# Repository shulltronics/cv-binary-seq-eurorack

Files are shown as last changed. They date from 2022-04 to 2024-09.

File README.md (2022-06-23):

## CV Binary Sequencer

This is a 1U Eurorack module that maps four trigger inputs to four CV outputs.
Inspired by the CV capabilities of Pamela's New Workout, _cv-binary-sequencer_ aims to produce customizable and intricate CV outputs for controlling other modules. There is a mapping of the 16 possible trigger inputs to a combination of CV outputs. On each trigger edge of an input CVs will change to the value specified by the mapping.

_cv-binary-seq_ can be used to multiplex 4 trigger inputs (e.g. 4 pads from a Beatstep Pro, or ) to create 16 different combinations of 4 CV outputs. This could be utilized to create 16 drum sounds from one module, or to create a 16 step melodic sequence that changes pitch, decay rate, and tone on each step.

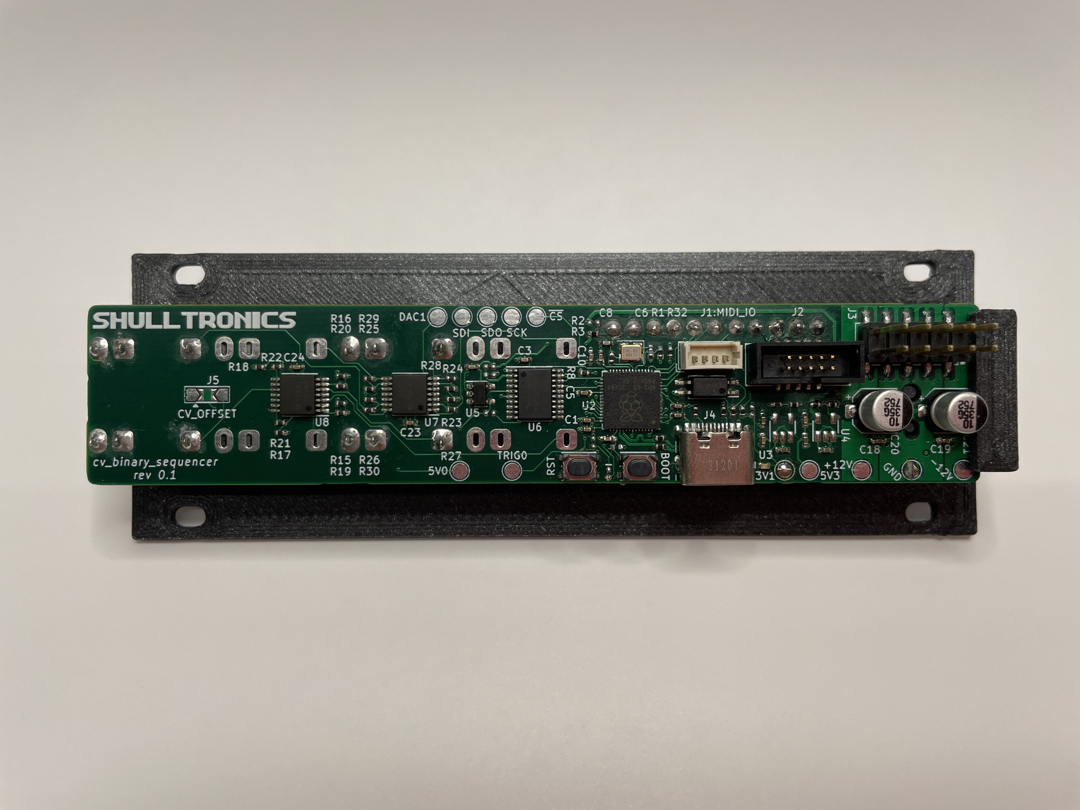
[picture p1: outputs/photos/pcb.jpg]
PCB Assembly

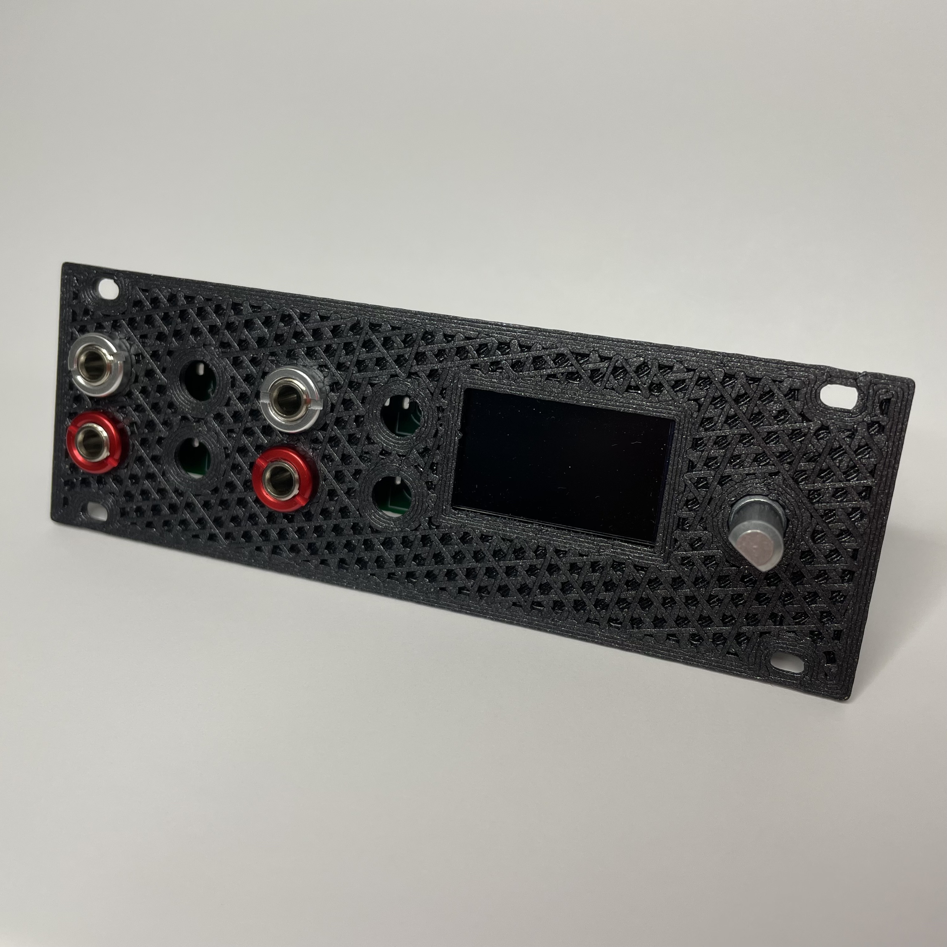
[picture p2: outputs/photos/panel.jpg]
Front Panel


### Goals
- [ ] - Configurable input trigger (rising, falling, etc). 
- [ ] - CV outputs similar to PNW (constant value, exponential rise/fall, period wave, etc).
- [ ] - Possibly add different input modes (binary mapping input to output, trigger input to cycle through mapping, etc).

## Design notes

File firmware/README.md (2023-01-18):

Firmware for CV Binary Sequencer
================================
### By Shulltronics

## Feature testing
- [X] USB firmware upload (**TODO** make connector double sided)
- [ ] BOOTSEL button (**Issue** don't think this will work without the ROM chip)
- [ ] USB Serial Comms (**Issue** don't think this will work without the ROM chip)
- [X] Status LED over GPIO
- [X] LCD screen over SPI (**TODO** Test various SPI speeds, look at signal integrity)
- [X] Encoder button over GPIO
- [ ] Encoder rotation (over PIO?)
- [ ] MIDI IO over UART
- [ ] Trigger inputs over Interrupts
- [X] DAC comms over SPI (**TODO** Improve driver)

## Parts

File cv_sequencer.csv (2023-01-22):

Source: | /home/carstentb/Projects/KiCad/cv-binary-seq-eurorack/cv_sequencer.kicad_sch
Date: | Sun 06 Nov 2022 12:24:42 PM EST
Tool: | Eeschema (6.0.9)
Generator: | /home/carstentb/.local/share/kicad/6.0/plugins/bom_csv_grouped_by_value.py
Component Count: | 90
Collated Components:
Item | Reference(s) | Qty | Distributor | Dist. PN | Value | SPN | Val
1 | C1, C2, C4, C5, C7, C9, C10, C11, C12, C14, C18, C19 | 12 | =FILTER('Parts Inventory'!G:H, 'Parts Inventory'!A:A=3089_Capacitor_100n_16V_0402) |  |  | 3089_Capacitor_100n_16V_0402 | 100n
2 | C3, C22, C23, C24 | 4 | =FILTER('Parts Inventory'!G:H, 'Parts Inventory'!A:A=3089_Capacitor_100n_16V_0402) |  |  | 3089_Capacitor_100n_16V_SMD | 100n
3 | C6, C8 | 2 | =FILTER('Parts Inventory'!G:H, 'Parts Inventory'!A:A=4003_Capacitor_22pF_50V_0402) |  |  | 4003_Capacitor_22pF_50V_0402 | 22pF
4 | C13, C15, C16, C17 | 4 | =FILTER('Parts Inventory'!G:H, 'Parts Inventory'!A:A=4035_Capacitor_2u2_25V_0402) |  |  | 4035_Capacitor_2u2_25V_0402 | 2u2
5 | C20, C21 | 2 | =FILTER('Parts Inventory'!G:H, 'Parts Inventory'!A:A=4031_Capacitor_10u_35V_SMD) |  |  | 4031_Capacitor_10u_35V_SMD | 10u
6 | E1 | 1 | =FILTER('Parts Inventory'!G:H, 'Parts Inventory'!A:A=4025_Encoder_Switch_SMD) |  |  | 4025_Encoder_Switch_SMD
7 | J1 | 1 | =FILTER('Parts Inventory'!G:H, 'Parts Inventory'!A:A=4029_Connector_PicoBlade_4pos_Vert_THT) |  |  | :MIDI_IO
8 | J2 | 1 | =FILTER('Parts Inventory'!G:H, 'Parts Inventory'!A:A=4005_SWD_Header) |  |  | SWD
9 | J3 | 1 | =FILTER('Parts Inventory'!G:H, 'Parts Inventory'!A:A=3086_Connector_Eurorack_Power) |  |  | 3086_Connector_Eurorack_Power
10 | J4 | 1 | =FILTER('Parts Inventory'!G:H, 'Parts Inventory'!A:A=3096_USBC_RA_SMD) |  |  | 3096_USBC_RA_SMD
11 | J5 | 1 | =FILTER('Parts Inventory'!G:H, 'Parts Inventory'!A:A=3046_Header_Male_Vert_3pos) |  |  | CV_OFFSET
12 | J6, J7, J8, J9, J10, J11, J12, J13 | 8 | =FILTER('Parts Inventory'!G:H, 'Parts Inventory'!A:A=3085_MiniJack_Thonk_Vert) |  |  | 3085_MiniJack_Thonk_Vert
13 | R1, R8, R32 | 3 | =FILTER('Parts Inventory'!G:H, 'Parts Inventory'!A:A=4008_Resistor_SMD_10k_0.125W_1%) |  |  | 4008_Resistor_SMD_10k_0.125W_1% | 10k
14 | R2, R38 | 2 | =FILTER('Parts Inventory'!G:H, 'Parts Inventory'!A:A=4021_Resistor_SMD_Jumper) |  |  | DNP | 0
15 | R3, R36 | 2 | =FILTER('Parts Inventory'!G:H, 'Parts Inventory'!A:A=4021_Resistor_SMD_Jumper) |  |  | 4021_Resistor_SMD_Jumper | 0
16 | R4, R5 | 2 | =FILTER('Parts Inventory'!G:H, 'Parts Inventory'!A:A=4010_Resistor_SMD_1k_0.125W_1%) |  |  | 4010_Resistor_SMD_1k_0.125W_1% | 1k
17 | R6, R7 | 2 | =FILTER('Parts Inventory'!G:H, 'Parts Inventory'!A:A=4011_Resistor_SMD_27_0.125W_1%) |  |  | 4011_Resistor_SMD_27_0.125W_1% | 27
18 | R9, R11 | 2 | =FILTER('Parts Inventory'!G:H, 'Parts Inventory'!A:A=4016_Resistor_SMD_27k_0.125W_1%) |  |  | 4016_Resistor_SMD_27k_0.125W_1% | 27k
19 | R10 | 1 | =FILTER('Parts Inventory'!G:H, 'Parts Inventory'!A:A=4033_Resistor_SMD_18k_0.125W_1%) |  |  | 4033_Resistor_SMD_18k_0.125W_1% | 18k
20 | R12 | 1 | =FILTER('Parts Inventory'!G:H, 'Parts Inventory'!A:A=4034_Resistor_SMD_8k2_0.125W_1%) |  |  | 4034_Resistor_SMD_8k2_0.125W_1% | 8k2
21 | R13, R14 | 2 | =FILTER('Parts Inventory'!G:H, 'Parts Inventory'!A:A=4009_Resistor_SMD_5k1_0.10W_1%) |  |  | 4009_Resistor_SMD_5k1_0.10W_1% | 5k1
22 | R15, R16, R17, R18 | 4 | =FILTER('Parts Inventory'!G:H, 'Parts Inventory'!A:A=4023_Resistor_SMD_56k_0.125W_1%) |  |  | 4023_Resistor_SMD_56k_0.125W_1% | 56k
23 | R19, R20, R21, R22 | 4 | =FILTER('Parts Inventory'!G:H, 'Parts Inventory'!A:A=4022_Resistor_SMD_120k_0.125W_1%) |  |  | 4022_Resistor_SMD_120k_0.125W_1% | 120k
24 | R23, R24, R25, R26, R27, R28, R29, R30 | 8 | =FILTER('Parts Inventory'!G:H, 'Parts Inventory'!A:A=4006_Resistor_SMD_68k_0.125W_1%) |  |  | 4006_Resistor_SMD_68k_0.125W_1% | 68k
25 | R31, R33 | 2 | =FILTER('Parts Inventory'!G:H, 'Parts Inventory'!A:A=4030_Resistor_SMD_220_0.125W_1%) |  |  | 4030_Resistor_SMD_220_0.125W_1% | 220
26 | R34, R35 | 2 | =FILTER('Parts Inventory'!G:H, 'Parts Inventory'!A:A=4038_Resistor_SMD_100_0.125W_1%) |  |  | 4038_Resistor_SMD_100_0.125W_1% | 100
27 | R37 | 1 | =FILTER('Parts Inventory'!G:H, 'Parts Inventory'!A:A=4021_Resistor_SMD_Jumper) |  |  | JMP | 0
28 | SW1 | 1 | =FILTER('Parts Inventory'!G:H, 'Parts Inventory'!A:A=4012_PushButton_NO_SMD) |  |  | RST
29 | SW2 | 1 | =FILTER('Parts Inventory'!G:H, 'Parts Inventory'!A:A=4012_PushButton_NO_SMD) |  |  | BOOT
30 | U1 | 1 | =FILTER('Parts Inventory'!G:H, 'Parts Inventory'!A:A=3097_TFT_Display_SPI) |  |  | 3097_TFT_Display_SPI | 1.14" TFT Display
31 | U2 | 1 | =FILTER('Parts Inventory'!G:H, 'Parts Inventory'!A:A=4002_RP2040) |  |  | 4002_RP2040
32 | U3, U4 | 2 | =FILTER('Parts Inventory'!G:H, 'Parts Inventory'!A:A=4032_Adjustable_Reg_200mA_SOT-23-5) |  |  | 4032_Adjustable_Reg_200mA_SOT-23-5
33 | U5 | 1 | =FILTER('Parts Inventory'!G:H, 'Parts Inventory'!A:A=4014_Voltage_Reference_5V_SOT23-6) |  |  | 4014_Voltage_Reference_5V_SOT23-6
34 | U6 | 1 | =FILTER('Parts Inventory'!G:H, 'Parts Inventory'!A:A=4001_MCP48FEB24_DAC) |  |  | 4001_MCP48FEB24_DAC
35 | U7, U8 | 2 | =FILTER('Parts Inventory'!G:H, 'Parts Inventory'!A:A=3099_TL074CPW_SMD) |  |  | 3099_TL074CPW_SMD | TL074
36 | U9 | 1 | =FILTER('Parts Inventory'!G:H, 'Parts Inventory'!A:A=4028_OptoIsolator_TLP290) |  |  | 4028_OptoIsolator_TLP290
37 | U10 | 1 | =FILTER('Parts Inventory'!G:H, 'Parts Inventory'!A:A=4036_LED_GRN_SMD) |  |  | PWR
38 | U11 | 1 | =FILTER('Parts Inventory'!G:H, 'Parts Inventory'!A:A=4037_LED_YLW_SMD) |  |  | STAT
39 | Y1 | 1 | =FILTER('Parts Inventory'!G:H, 'Parts Inventory'!A:A=4004-Crystal-12MHz_GND24) |  |  | 4004-Crystal-12MHz_GND24 | 12.00MHz

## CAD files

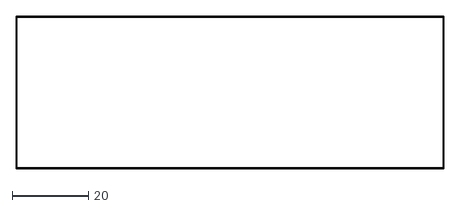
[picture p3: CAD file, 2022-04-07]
outputs/panel_dxf/cv_sequencer-User_Eco1.dxf
111.9 x 39.8

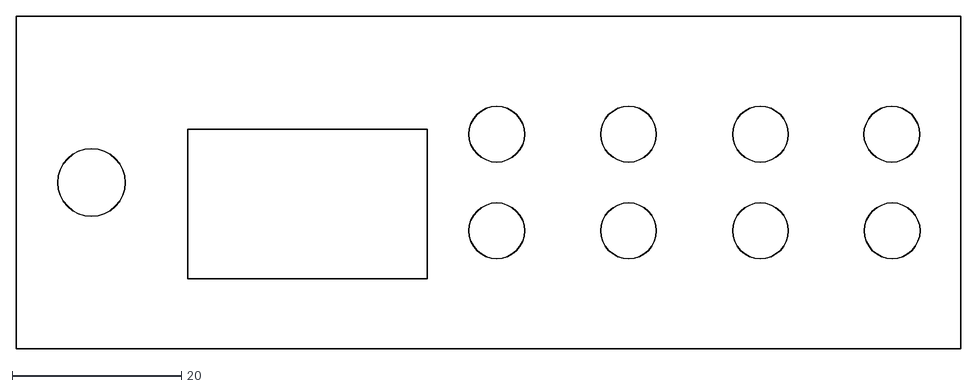
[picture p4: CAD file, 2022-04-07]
outputs/panel_dxf/drawing.dxf
111.8 x 39.4

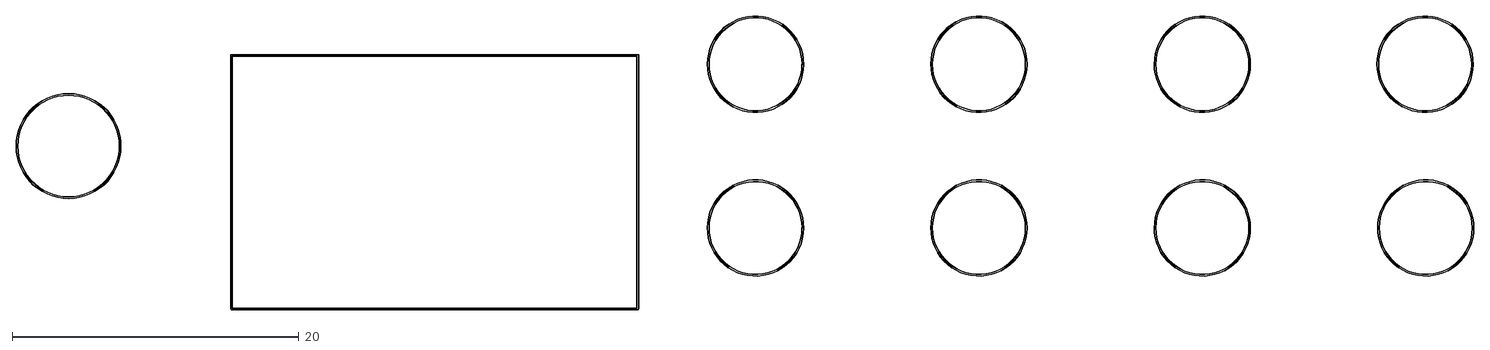
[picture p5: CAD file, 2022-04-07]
outputs/panel_dxf/cv_sequencer-User_Drawings.dxf
101.8 x 20.5

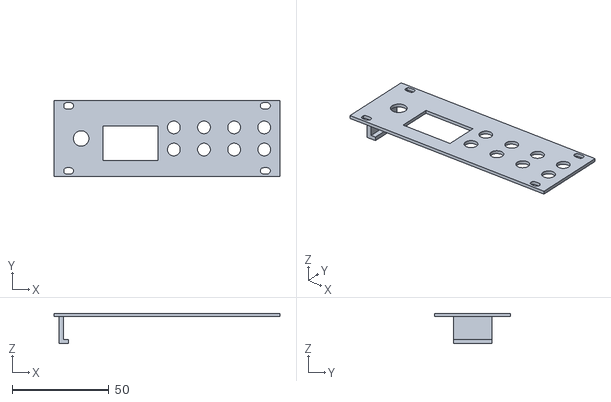
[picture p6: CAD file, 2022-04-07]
outputs/panel_dxf/panel_with_support.stl
116.9 x 39.5 x 15.6

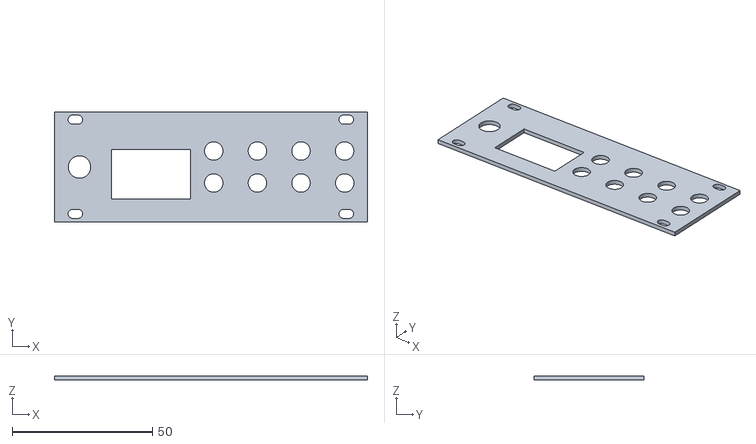
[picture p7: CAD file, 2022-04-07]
outputs/panel_dxf/panel.stl
111.8 x 39.4 x 1.60

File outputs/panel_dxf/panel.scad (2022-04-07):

_DELTA = 0.01;

ONE_HP = 0.2*25.4;
ONE_U  = 39.65;
// approximately equal to a standard PCB thickness
THICKNESS = 1.6;
MODULE_WIDTH = 23*ONE_HP;

// the main facade body
//   Process: plot User Drawings layer from KiCAD (contains outline
//     and holes for jacks, encoders, etc). Open that in Inkscape,
//     process circles using "Object->Object to Path", then select path,
//     process using "Segments to lines", then save as R14 DXF to import here.
module main() {
    linear_extrude(height=THICKNESS)
        import(file="drawing.dxf");
}

module mounting_hole(x_offset=0, y_offset=0) {
    $fn = 36;
    MOUNTING_HOLE_DIAMETER = 3.2;
    translate([x_offset, y_offset, THICKNESS/2])
        hull() {
            translate([-1, 0, 0])
                cylinder(THICKNESS+_DELTA, MOUNTING_HOLE_DIAMETER/2, MOUNTING_HOLE_DIAMETER/2, center=true);
            translate([1, 0, 0])
                cylinder(THICKNESS+_DELTA, MOUNTING_HOLE_DIAMETER/2, MOUNTING_HOLE_DIAMETER/2, center=true);
        }
}

module three() {
    
}

difference() {  
    translate([1*ONE_HP, 0, 0])
        main();
    mounting_hole(7.5, 3);
    mounting_hole(7.5, ONE_U-3);
    mounting_hole(MODULE_WIDTH-7.5, 3);
    mounting_hole(MODULE_WIDTH-7.5, ONE_U-3);
}

// extra space to add support
cube([ONE_HP+10*_DELTA, ONE_U-0.2, THICKNESS]);
translate([2.5, 0, 0]) {
    // support
    support_height = 12;
    translate([ONE_HP/4, ONE_U/2, -support_height/2])
        cube([ONE_HP/2, ONE_U/2, support_height], center=true);
    translate([ONE_HP/2, ONE_U/2, -support_height-1])
        cube([ONE_HP, ONE_U/2, 2], center=true);
}

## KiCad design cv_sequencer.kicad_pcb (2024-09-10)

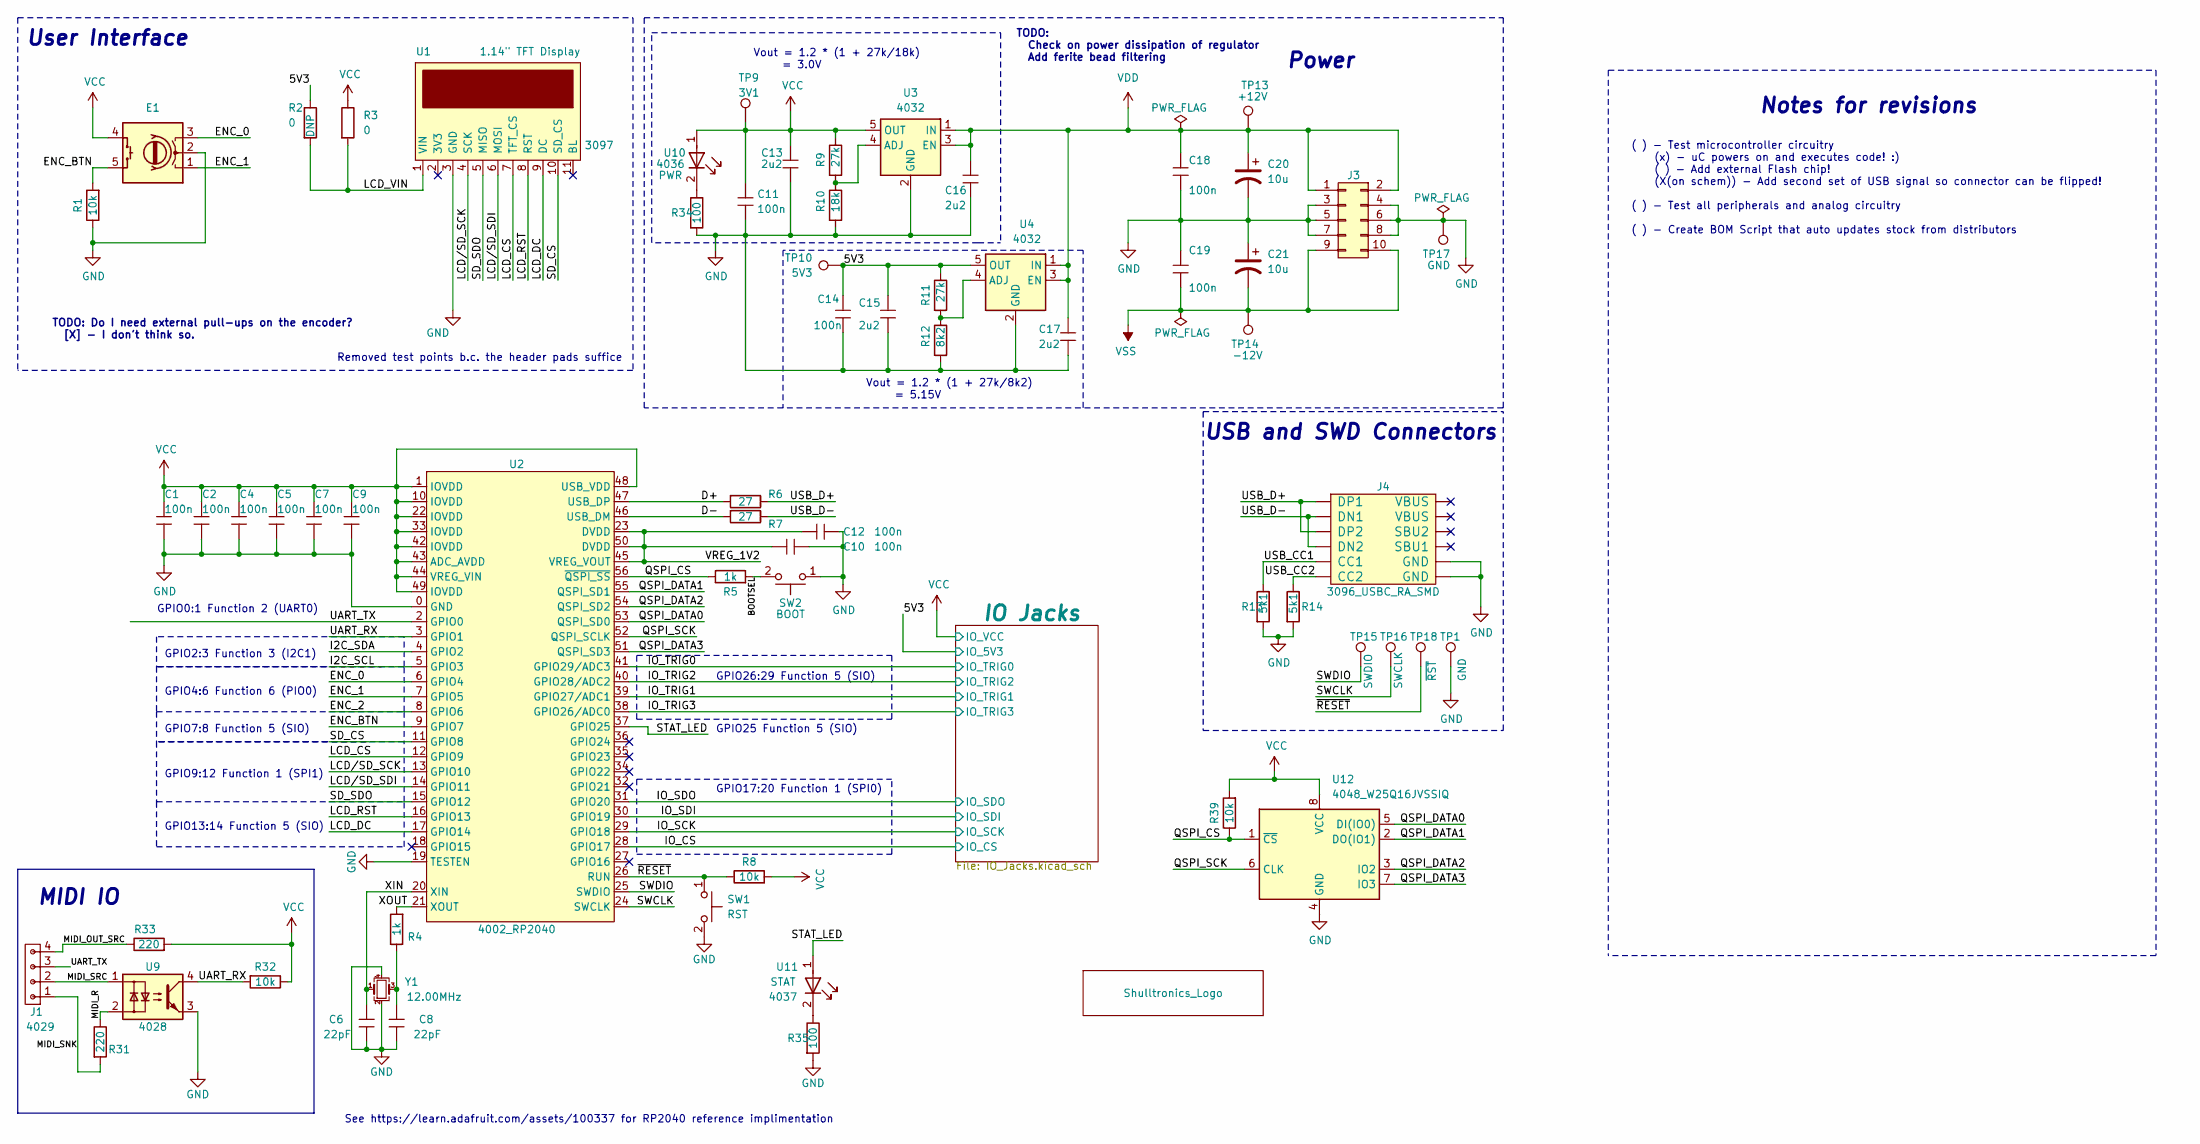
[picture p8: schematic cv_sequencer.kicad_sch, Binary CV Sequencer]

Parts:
C1, C2, C4, C5, C7, C9, C10, C11, C12, C14, C18, C19: 3089_Capacitor_100n_16V_0402; C_0402_HandSolder
C6, C8: 4003_Capacitor_22pF_50V_0402; C_0402_HandSolder
C13, C15, C16, C17: 4035_Capacitor_2u2_25V_0402; C_0402_HandSolder
C20, C21: 4031_Capacitor_10u_35V_SMD; 3088_Capacitor_10u_50V_SMD
E1: 4025_Encoder_Switch_SMD; 4025_Encoder_PEC11S
J1: :MIDI_IO; 4029_PicoBlade_4pos_Vert_THT
J3: 3086_Connector_Eurorack_Power; 3086_SMD_Eurorack_Power
J4: 3096_USBC_RA_SMD; 3096_USBC_RA
L1: Shulltronics_Logo
R1, R8, R32, R39: 4008_Resistor_SMD_10k_0.125W_1%; RES-0402
R2: DNP; RES-0402
R3: 4021_Resistor_SMD_Jumper; RES-0402
R4, R5: 4010_Resistor_SMD_1k_0.125W_1%; RES-0402
R6, R7: 4011_Resistor_SMD_27_0.125W_1%; RES-0402
R9, R11: 4016_Resistor_SMD_27k_0.125W_1%; RES-0402
R10: 4033_Resistor_SMD_18k_0.125W_1%; RES-0402
R12: 4034_Resistor_SMD_8k2_0.125W_1%; RES-0402
R13, R14: 4009_Resistor_SMD_5k1_0.10W_1%; RES-0402
R31, R33: 4030_Resistor_SMD_220_0.125W_1%; RES-0402
R34, R35: 4038_Resistor_SMD_100_0.125W_1%; RES-0402
SW1: RST; 4012_PushButton_NO_SMD
SW2: BOOT; 4012_PushButton_NO_SMD
TP1, TP17: GND; TestPoint_Pad_D2.0mm
TP9: 3V1; TestPoint_Pad_D2.0mm
TP10: 5V3; TestPoint_Pad_D2.0mm
TP13: +12V; TestPoint_Pad_D2.0mm
TP14: -12V; TestPoint_Pad_D2.0mm
TP15: SWDIO; TestPoint_Pad_D2.0mm
TP16: SWCLK; TestPoint_Pad_D2.0mm
TP18: ~{RST}; TestPoint_Pad_D2.0mm
U1: 3097_TFT_Display_SPI
U2: 4002_RP2040; 4002_RP2040_QFN-56-7x7mm_P0.4mm
U3, U4: 4032_Adjustable_Reg_200mA_SOT-23-5; SOT-23-5
U9: 4028_OptoIsolator_TLP290; 4028_OptoIsolator_TLP290_SOP-4
U10: PWR; LED_0402
U11: STAT; LED_0402
U12: 4048_W25Q16JVSSIQ; 4048_16Mb_Flash_SOIC8
Y1: 4004-Crystal-12MHz_GND24; 4004-Crystal-12MHz-4Pin_2.5x2.0mm

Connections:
/5V3: C14.2, C15.2, R2.1, R11.1, TP10.1, U4.5 (OUT); also elsewhere on the board
/BOOTSEL: R5.2, SW2.2
/D+: R6.2, U2.47 (USB_DP)
/D-: R7.2, U2.46 (USB_DM)
/ENC_0: E1.3, U2.6 (GPIO4)
/ENC_1: E1.1, U2.7 (GPIO5)
/ENC_2: U2.8 (GPIO6)
/ENC_BTN: E1.5, R1.2, U2.9 (GPIO7)
/I2C_SCL: U2.5 (GPIO3)
/I2C_SDA: U2.4 (GPIO2)
/IO_CS: U2.28 (GPIO17); also elsewhere on the board
/IO_SCK: U2.29 (GPIO18); also elsewhere on the board
/IO_SDI: U2.30 (GPIO19); also elsewhere on the board
/IO_SDO: U2.31 (GPIO20); also elsewhere on the board
/IO_TRIG0: U2.41 (GPIO29/ADC3); also elsewhere on the board
/IO_TRIG1: U2.39 (GPIO27/ADC1); also elsewhere on the board
/IO_TRIG2: U2.40 (GPIO28/ADC2); also elsewhere on the board
/IO_TRIG3: U2.38 (GPIO26/ADC0); also elsewhere on the board
/LCD_CS: U1.7 (TFT_CS), U2.12 (GPIO9)
/LCD_DC: U1.9 (DC), U2.17 (GPIO14)
/LCD_RST: U1.8 (RST), U2.16 (GPIO13)
/LCD_VIN: R2.2, R3.2, U1.1 (VIN)
/LCD/SD_SCK: U1.4 (SCK), U2.13 (GPIO10)
/LCD/SD_SDI: U1.6 (MOSI), U2.14 (GPIO11)
/MIDI_OUT_SRC: J1.4, R33.1
/MIDI_R: R31.1, U9.2
/MIDI_SNK: J1.1, R31.2
/MIDI_SRC: J1.2, U9.1
/QSPI_CS: R5.1, R39.1, U2.56 (~QSPI_SS), U12.1 (~CS)
/QSPI_DATA0: U2.53 (QSPI_SD0), U12.5 (DI(IO0))
/QSPI_DATA1: U2.55 (QSPI_SD1), U12.2 (DO(IO1))
/QSPI_DATA2: U2.54 (QSPI_SD2), U12.3 (IO2)
/QSPI_DATA3: U2.51 (QSPI_SD3), U12.7 (IO3)
/QSPI_SCK: U2.52 (QSPI_SCLK), U12.6 (CLK)
/SD_CS: U1.10 (SD_CS), U2.11 (GPIO8)
/SD_SDO: U1.5 (MISO), U2.15 (GPIO12)
/STAT_LED: U2.37 (GPIO25), U11.1 (A)
/SWCLK: TP16.1, U2.24 (SWCLK)
/SWDIO: TP15.1, U2.25 (SWDIO)
/UART_RX: R32.2, U2.3 (GPIO1), U9.4
/UART_TX: J1.3, U2.2 (GPIO0)
/USB_CC1: J4.A5 (CC1), R13.1
/USB_CC2: J4.B5 (CC2), R14.1
/USB_D+: J4.A6 (DP1), J4.B6 (DP2), R6.1
/USB_D-: J4.A7 (DN1), J4.B7 (DN2), R7.1
/VREG_1V2: C10.1, C12.1, U2.23 (DVDD), U2.45 (VREG_VOUT), U2.50 (DVDD)
/XIN: C6.2, U2.20 (XIN), Y1.1
/XOUT: R4.2, U2.21 (XOUT)
/~RESET: R8.1, SW1.1, TP18.1, U2.26 (RUN)
GND: C1.1, C2.1, C4.1, C5.1, C6.1, C7.1, C8.1, C9.1, C10.2, C11.1, C12.2, C13.1, C14.1, C15.1, C16.1, C17.1, C18.1, C19.2, C20.2, C21.1, E1.2, J3.3, J3.4, J3.5, J3.6, J3.7, J3.8, J4.A1/B12 (GND), J4.B1/A12 (GND), R1.1, R10.2, R12.2, R13.2, R14.2, R34.2, R35.2, SW1.2, SW2.1, TP1.1, TP17.1, U1.3 (GND), U2.0 (GND), U2.19 (TESTEN), U3.2 (GND), U4.2 (GND), U9.3, U12.4 (GND), Y1.2, Y1.4; also elsewhere on the board
unnamed: C8.2, R4.1, Y1.3
unnamed: R9.2, R10.1, U3.4 (ADJ)
unnamed: R11.2, R12.1, U4.4 (ADJ)
unnamed: R34.1, U10.2 (K)
unnamed: R35.1, U11.2 (K)
VCC: C1.2, C2.2, C4.2, C5.2, C7.2, C9.2, C11.2, C13.2, E1.4, R3.1, R8.2, R9.1, R32.1, R33.2, R39.2, TP9.1, U2.1 (IOVDD), U2.10 (IOVDD), U2.22 (IOVDD), U2.33 (IOVDD), U2.42 (IOVDD), U2.43 (ADC_AVDD), U2.44 (VREG_VIN), U2.48 (USB_VDD), U2.49 (IOVDD), U3.5 (OUT), U10.1 (A), U12.8 (VCC); also elsewhere on the board
VDD: C16.2, C17.2, C18.2, C20.1, J3.1, J3.2, TP13.1, U3.1 (IN), U3.3 (EN), U4.1 (IN), U4.3 (EN); also elsewhere on the board
VSS: C19.1, C21.2, J3.9, J3.10, TP14.1; also elsewhere on the board

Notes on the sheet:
GPIO25 Function 5 (SIO)
Vout = 1.2 * (1 + 27k/8k2) = 5.15V
GPIO2:3 Function 3 (I2C1)
GPIO17:20 Function 1 (SPI0)
Removed test points b.c. the header pads suffice
See https://learn.adafruit.com/assets/100337 for RP2040 reference implimentation
Vout = 1.2 * (1 + 27k/18k) = 3.0V
GPIO7:8 Function 5 (SIO)
USB and SWD Connectors
( ) - Test microcontroller circuitry (x) - uC powers on and executes code! :) ( ) - Add external Flash chip! (X(on schem)) - Add second set of USB signal so connector can be flipped! ( ) - Test all peripherals and analog circuitry ( ) - Create BOM Script that auto updates stock from distributors
GPIO9:12 Function 1 (SPI1)
TODO: Do I need external pull-ups on the encoder? [X] - I don't think so.
Notes for revisions
MIDI IO
GPIO0:1 Function 2 (UART0)
GPIO26:29 Function 5 (SIO)
Power
TODO: Check on power dissipation of regulator Add ferite bead filtering
GPIO13:14 Function 5 (SIO)
GPIO4:6 Function 6 (PIO0)
User Interface

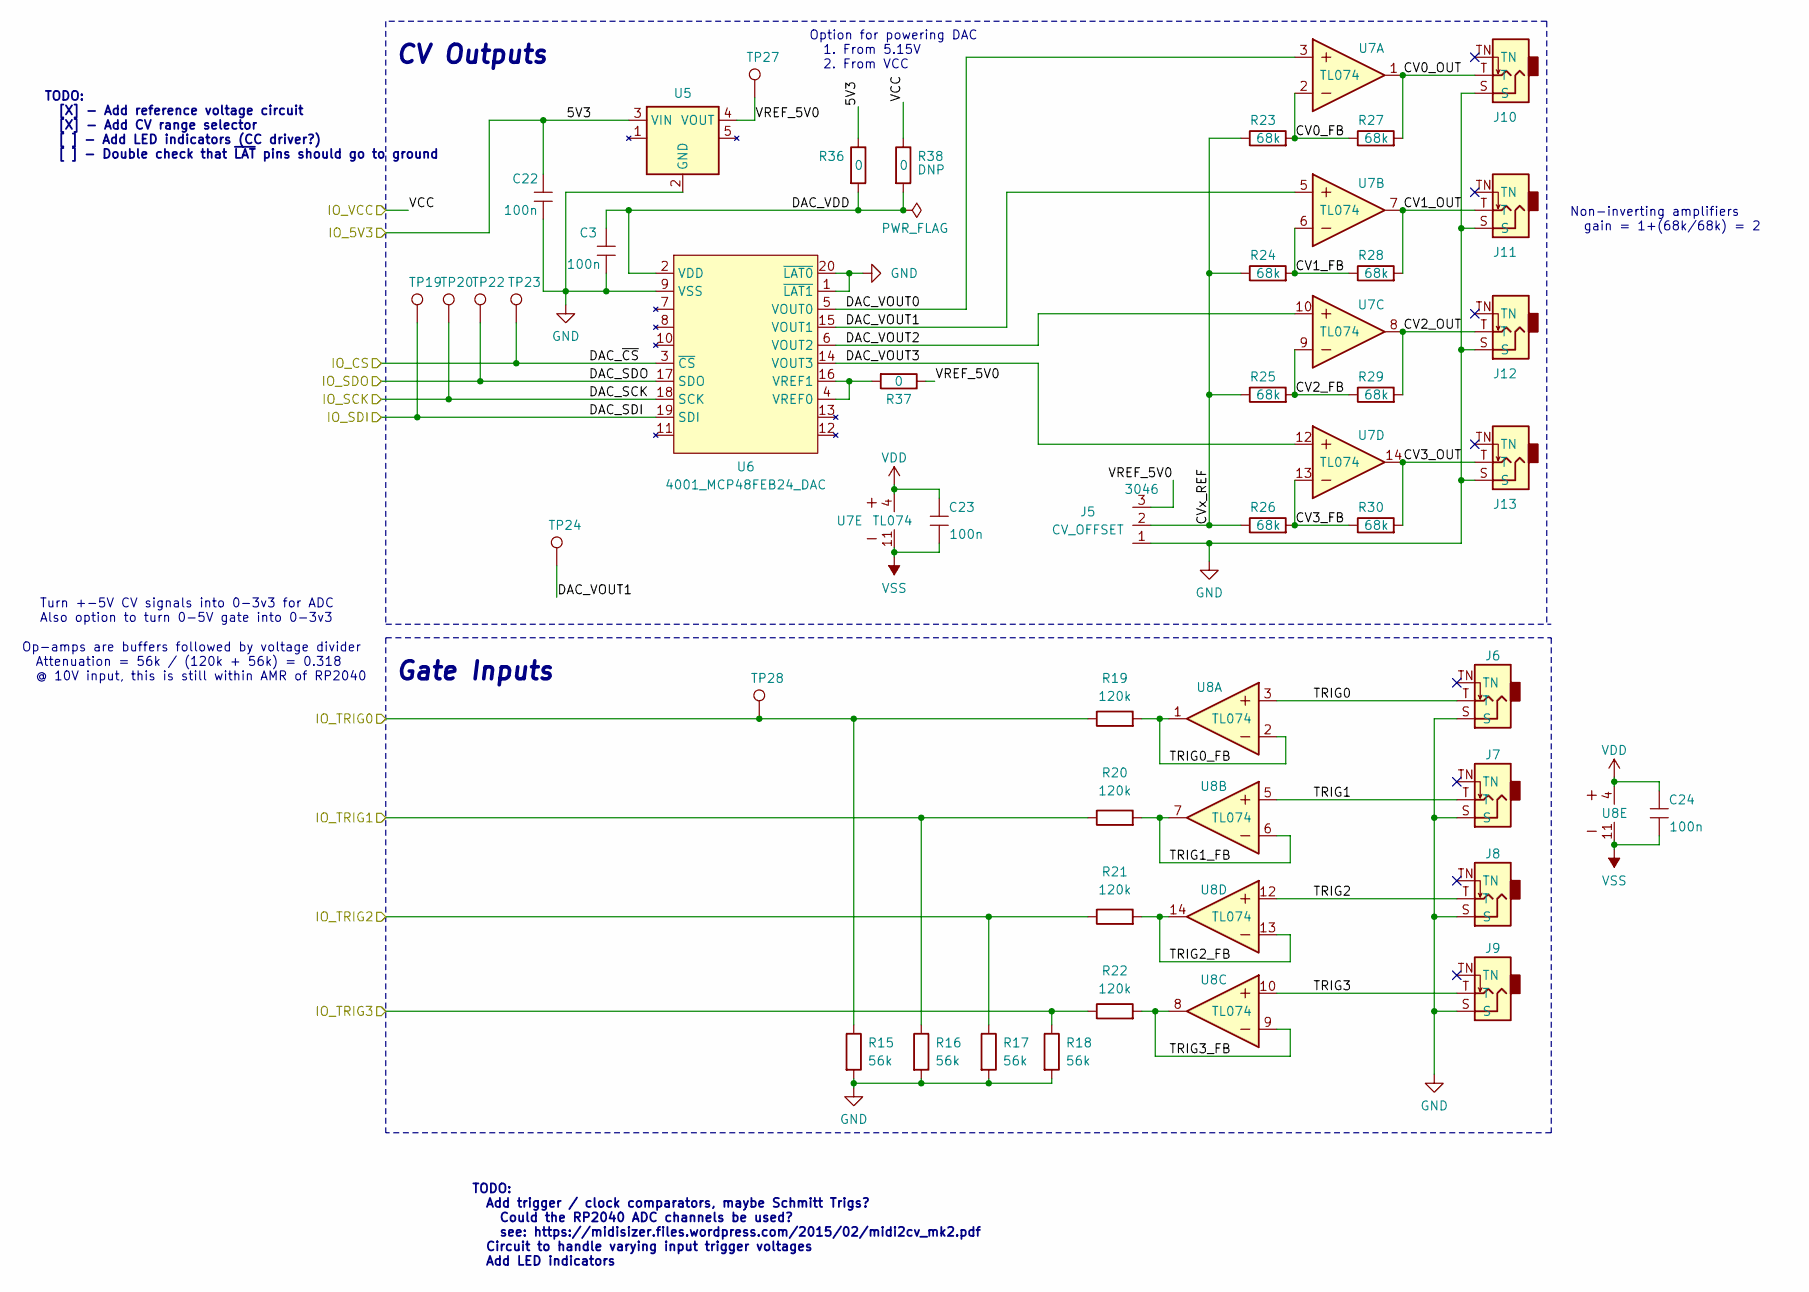
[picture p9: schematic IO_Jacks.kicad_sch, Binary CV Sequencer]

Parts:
C3, C22, C23, C24: 3089_Capacitor_100n_16V_SMD; C_0402_HandSolder
J5: CV_OFFSET; SMD_SolderJumper-3
J6, J7, J8, J9, J10, J11, J12, J13: 3085_MiniJack_Thonk_Vert
R15, R16, R17, R18: 4023_Resistor_SMD_56k_0.125W_1%; RES-0402
R19, R20, R21, R22: 4022_Resistor_SMD_120k_0.125W_1%; RES-0402
R23, R24, R25, R26, R27, R28, R29, R30: 4006_Resistor_SMD_68k_0.125W_1%; RES-0402
R36: 4021_Resistor_SMD_Jumper; RES-0402
R37: JMP; RES-0402
R38: DNP; RES-0402
TP19: SDI; TestPoint_Pad_D2.0mm
TP20: SCK; TestPoint_Pad_D2.0mm
TP22: SDO; TestPoint_Pad_D2.0mm
TP23: ~{CS}; TestPoint_Pad_D2.0mm
TP24: DAC1; TestPoint_Pad_D2.0mm
TP27: 5V0; TestPoint_Pad_D2.0mm
TP28: TRIG0; TestPoint_Pad_D2.0mm
U5: 4014_Voltage_Reference_5V_SOT23-6; SOT-23-5
U6: 4001_MCP48FEB24_DAC; TSSOP-20_4.4x6.5mm_P0.65mm
U7, U8: 3099_TL074CPW_SMD; 3099_TL074CPW_TSSOP14

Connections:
/5V3: C22.2, R36.1, U5.3 (VIN); also elsewhere on the board
/IO Jacks/CV0_FB: R23.2, R27.1, U7.2 (1IN-)
/IO Jacks/CV0_OUT: J10.T, R27.2, U7.1 (1OUT)
/IO Jacks/CV1_FB: R24.2, R28.1, U7.6 (2IN-)
/IO Jacks/CV1_OUT: J11.T, R28.2, U7.7 (2OUT)
/IO Jacks/CV2_FB: R25.2, R29.1, U7.9 (3IN-)
/IO Jacks/CV2_OUT: J12.T, R29.2, U7.8 (3OUT)
/IO Jacks/CV3_FB: R26.2, R30.1, U7.13 (4IN-)
/IO Jacks/CV3_OUT: J13.T, R30.2, U7.14 (4OUT)
/IO Jacks/CVx_REF: J5.2, R23.1, R24.1, R25.1, R26.1
/IO Jacks/DAC_VDD: C3.2, R36.2, R38.2, U6.2 (VDD)
/IO Jacks/DAC_VOUT0: U6.5 (VOUT0), U7.3 (1IN+)
/IO Jacks/DAC_VOUT1: TP24.1, U6.15 (VOUT1), U7.5 (2IN+)
/IO Jacks/DAC_VOUT2: U6.6 (VOUT2), U7.10 (3IN+)
/IO Jacks/DAC_VOUT3: U6.14 (VOUT3), U7.12 (4IN+)
/IO Jacks/TRIG0: J6.T, U8.3 (1IN+)
/IO Jacks/TRIG0_FB: R19.2, U8.1 (1OUT), U8.2 (1IN-)
/IO Jacks/TRIG1: J7.T, U8.5 (2IN+)
/IO Jacks/TRIG1_FB: R20.2, U8.6 (2IN-), U8.7 (2OUT)
/IO Jacks/TRIG2: J8.T, U8.12 (4IN+)
/IO Jacks/TRIG2_FB: R21.2, U8.13 (4IN-), U8.14 (4OUT)
/IO Jacks/TRIG3: J9.T, U8.10 (3IN+)
/IO Jacks/TRIG3_FB: R22.2, U8.8 (3OUT), U8.9 (3IN-)
/IO Jacks/VREF_5V0: J5.3, R37.1, TP27.1, U5.4 (VOUT)
/IO_CS: TP23.1, U6.3 (~CS); also elsewhere on the board
/IO_SCK: TP20.1, U6.18 (SCK); also elsewhere on the board
/IO_SDI: TP19.1, U6.19 (SDI); also elsewhere on the board
/IO_SDO: TP22.1, U6.17 (SDO); also elsewhere on the board
/IO_TRIG0: R15.1, R19.1, TP28.1; also elsewhere on the board
/IO_TRIG1: R16.1, R20.1; also elsewhere on the board
/IO_TRIG2: R17.1, R21.1; also elsewhere on the board
/IO_TRIG3: R18.1, R22.1; also elsewhere on the board
GND: C3.1, C22.1, J5.1, J6.S, J7.S, J8.S, J9.S, J10.S, J11.S, J12.S, J13.S, R15.2, R16.2, R17.2, R18.2, U5.2 (GND), U6.1 (~LAT1), U6.9 (VSS), U6.20 (~LAT0); also elsewhere on the board
unnamed: R37.2, U6.4 (VREF0), U6.16 (VREF1)
VCC: R38.1; also elsewhere on the board
VDD: C23.2, C24.2, U7.4 (VCC), U8.4 (VCC); also elsewhere on the board
VSS: C23.1, C24.1, U7.11 (VEE), U8.11 (VEE); also elsewhere on the board

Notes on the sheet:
TODO: [X] - Add reference voltage circuit [X] - Add CV range selector [ ] - Add LED indicators (CC driver?) [ ] - Double check that ~{LAT} pins should go to ground
Gate Inputs
Turn +-5V CV signals into 0-3v3 for ADC Also option to turn 0-5V gate into 0-3v3
CV Outputs
Op-amps are buffers followed by voltage divider Attenuation = 56k / (120k + 56k) = 0.318 @ 10V input, this is still within AMR of RP2040
Option for powering DAC 1. From 5.15V 2. From VCC
TODO: Add trigger / clock comparators, maybe Schmitt Trigs? Could the RP2040 ADC channels be used? see: https://midisizer.files.wordpress.com/2015/02/midi2cv_mk2.pdf Circuit to handle varying input trigger voltages Add LED indicators
Non-inverting amplifiers gain = 1+(68k/68k) = 2

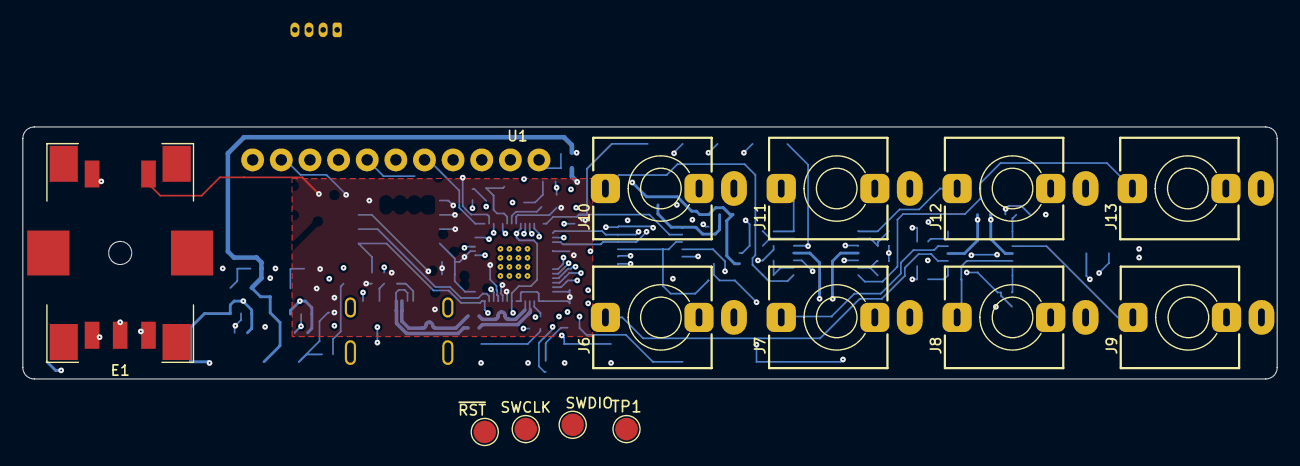
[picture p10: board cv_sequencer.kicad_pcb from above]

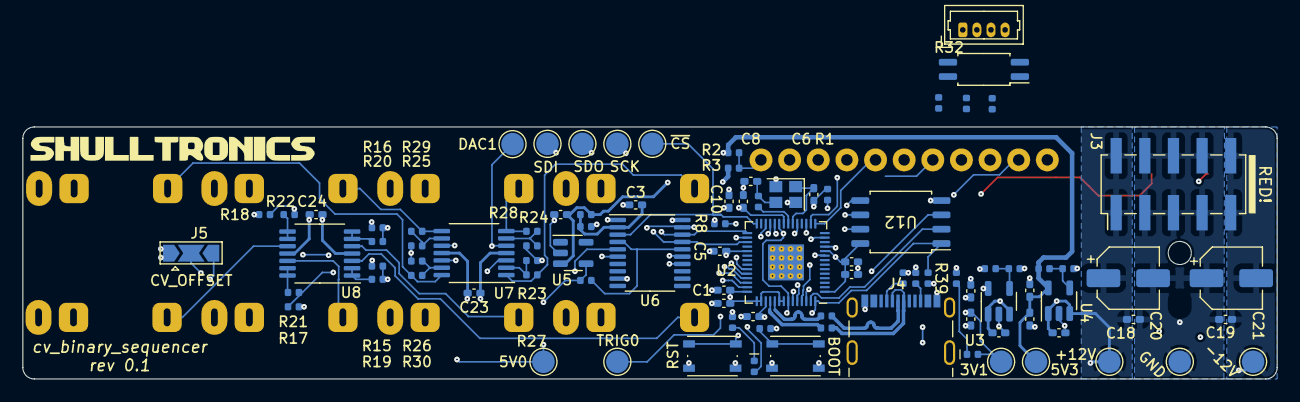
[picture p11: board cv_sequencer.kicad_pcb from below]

Board: 4 copper layers, 111.3 x 22.4 mm, 108 parts (94 on the bottom side), 79 nets.

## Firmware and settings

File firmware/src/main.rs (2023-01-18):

#![no_std]
#![no_main]

use panic_halt as _;
use cortex_m::prelude::*;
use cortex_m_rt::entry;
use embedded_hal::{
    digital::v2::{OutputPin, InputPin}
};
// use embedded_time::rate::*;
use fugit::RateExtU32;  // allows the .to_Hz() method
use rp2040_hal as hal;
use hal::{
    clocks::{init_clocks_and_plls, Clock},
    pac,
    pac::interrupt,
    watchdog::Watchdog,
    Sio,
    gpio::Pins,
};

use display_interface_spi::SPIInterface;
use st7789::{Orientation, ST7789};
use embedded_graphics::{
    prelude::*,
    primitives::*,
    pixelcolor::Rgb565,
    mono_font::{ascii::FONT_6X9, MonoTextStyle},
    text::Text,
};

mod mcp48fxbxx;
use mcp48fxbxx::MCP48FXBxx;

/// The linker will place this boot block at the start of our program image. We
/// need this to help the ROM bootloader get our code up and running.
#[link_section = ".boot2"]
#[used]
pub static BOOT2: [u8; 256] = rp2040_boot2::BOOT_LOADER_RAM_MEMCPY;
const XTAL_OSC_FREQ: u32 = 12_000_000;

// USB Device support
// use usb_device::class_prelude::*;
// // USB Communications Class Device support
// mod usb_manager;
// use usb_manager::UsbManager;
// /******************************************************************************
//      Global USB objects & interrupt
// ******************************************************************************/
// static mut USB_BUS: Option<UsbBusAllocator<hal::usb::UsbBus>> = None;
// static mut USB_MANAGER: Option<UsbManager> = None;
// #[allow(non_snake_case)]
// #[interrupt]
// unsafe fn USBCTRL_IRQ() {
//     match USB_MANAGER.as_mut() {
//         Some(manager) => manager.interrupt(),
//         None => (),
//     };
// }

#[entry]
fn main() -> ! {
    // initialization code here
    let mut pac = pac::Peripherals::take().unwrap();
    let core = pac::CorePeripherals::take().unwrap();
    let mut watchdog = Watchdog::new(pac.WATCHDOG);

    let clocks = init_clocks_and_plls(
        XTAL_OSC_FREQ,
        pac.XOSC,
        pac.CLOCKS,
        pac.PLL_SYS,
        pac.PLL_USB,
        &mut pac.RESETS,
        &mut watchdog,
    ).ok().unwrap();

    let sio = Sio::new(pac.SIO);
    let pins = Pins::new(
        pac.IO_BANK0,
        pac.PADS_BANK0,
        sio.gpio_bank0,
        &mut pac.RESETS,
    );

    // Setup USB
    // let usb = unsafe {
    //     USB_BUS = Some(UsbBusAllocator::new(hal::usb::UsbBus::new(
    //         pac.USBCTRL_REGS,
    //         pac.USBCTRL_DPRAM,
    //         clocks.usb_clock,
    //         true,
    //         &mut pac.RESETS,
    //     )));
    //     USB_MANAGER = Some(UsbManager::new(USB_BUS.as_ref().unwrap()));
    //     // Enable the USB interrupt
    //     pac::NVIC::unmask(hal::pac::Interrupt::USBCTRL_IRQ);
    //     USB_MANAGER.as_mut().unwrap()
    // };


    let mut timer = cortex_m::delay::Delay::new(core.SYST, clocks.system_clock.freq().to_Hz());
    
    // general purpose testing pin (goes to unpopulated LED for now)
    let mut status_pin = pins.gpio25.into_push_pull_output();
    status_pin.set_high().unwrap();
    let encoder_button = pins.gpio7.into_pull_down_input();

    // pins for use with ST7789 LCD
    let _lcd_cs  = pins.gpio9.into_push_pull_output();
    let _lcd_sclk = pins.gpio10.into_mode::<hal::gpio::FunctionSpi>();
    let _lcd_mosi = pins.gpio11.into_mode::<hal::gpio::FunctionSpi>();
    let _lcd_miso = pins.gpio12.into_mode::<hal::gpio::FunctionSpi>();
    let _lcd_rst = pins.gpio13.into_push_pull_output();
    let _lcd_dc  = pins.gpio14.into_push_pull_output();
    // // initialize the SPI module
    let spi = hal::Spi::<_, _, 8>::new(pac.SPI1);
    let mut spi = spi.init(
        &mut pac.RESETS,
        clocks.peripheral_clock.freq(),
        10_000_000u32.Hz(),
        &embedded_hal::spi::MODE_3,
    );
    // create the SPI "display interface"
    let di = SPIInterface::new(spi, _lcd_dc, _lcd_cs);
    let mut lcd = ST7789::new(di, _lcd_rst, 240, 135);
    // // initialize the display and set its orientation
    lcd.init(&mut timer).unwrap();
    lcd.set_orientation(Orientation::Landscape).unwrap();

    // let line = Line::new(Point::new(0, 0), Point::new(100, 100))
    //     .into_styled(PrimitiveStyle::with_stroke(Rgb565::WHITE, 1));
    lcd.clear(Rgb565::WHITE).unwrap();
    // line.draw(&mut lcd).unwrap();

    let style = MonoTextStyle::new(&FONT_6X9, Rgb565::RED);
    let mut text = Text::new("hello, rust!", Point::new(100, 100), style);
    
    /**************************************************************************
    MCP DAC Setup and Testing
    **************************************************************************/
    let _dac_cs   = pins.gpio17.into_push_pull_output();
    let _dac_sclk = pins.gpio18.into_mode::<hal::gpio::FunctionSpi>();
    let _dac_mosi = pins.gpio19.into_mode::<hal::gpio::FunctionSpi>();
    let _dac_miso = pins.gpio20.into_mode::<hal::gpio::FunctionSpi>();
    // // initialize the SPI module
    let spi0 = hal::Spi::<_, _, 8>::new(pac.SPI0);
    let mut spi0 = spi0.init(
        &mut pac.RESETS,
        clocks.peripheral_clock.freq(),
        10_000_000u32.Hz(),
        &embedded_hal::spi::MODE_3,
    );
    // Create the driver object
    let mut dac = MCP48FXBxx::new(spi0, _dac_cs);
    dac.init();
    // try reading from a register
    let res = dac.read();
    // dac.write(0xAA);
    dac.setup();

    // loop code here
    let mut old_button_state: bool = false;
    loop {
        let current_button_state: bool = encoder_button.is_high().unwrap();
        let button_changed: bool = (old_button_state != current_button_state);
        if button_changed {
            old_button_state = current_button_state;
            if current_button_state == true {
                text.draw(&mut lcd).unwrap();
            } else {
                lcd.clear(Rgb565::BLACK).unwrap();
            }
        }
    }
}

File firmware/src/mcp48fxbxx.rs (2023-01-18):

use embedded_hal::spi;

// An enumeration of the device status and control registers
// for non-volatile versions, add 0x10
#[repr(u8)]
pub enum Instruction {
    DAC0_REG       = 0x00,
    DAC1_REG       = 0x01,
    DAC2_REG       = 0x02,
    DAC3_REG       = 0x03,
    DAC4_REG       = 0x04,
    DAC5_REG       = 0x05,
    DAC6_REG       = 0x06,
    DAC7_REG       = 0x07,
    VREF_REG       = 0x08,
    PWR_REG        = 0x09,
    GAIN_STAT      = 0x0A,
    WIPERLOCK_STAT = 0x0B,
}

// The main DAC struct, with SPI interface
pub struct MCP48FXBxx<SPI, CS>
{
    spi: SPI,
    cs: CS,
}

impl<SPI, CS> MCP48FXBxx<SPI, CS>
where
    SPI: embedded_hal::blocking::spi::Write<u8>,
    CS:  embedded_hal::digital::v2::OutputPin,
{
    pub fn new(spi: SPI, cs: CS) -> Self {
        Self {spi, cs}
    }

    pub fn init(&mut self) {
        self.cs.set_high();
    }

    pub fn read(&self) {

    }

    pub fn write(&mut self, data: u8) {
        let buf = [data];
        // drive the CS pin low
        self.cs.set_low();
        self.spi.write(&buf);
        self.cs.set_high();
    }

    // test method to write data to device
    pub fn setup(&mut self) {
        // I think this would set DAC1 output to full voltage
        let buf = [0x01 << 3 | 0b000, 0x0F, 0xFF];
        self.cs.set_low();
        self.spi.write(&buf);
        self.cs.set_high();
    }
}

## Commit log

2022-03-09 Start tracking work on this project
    [IO_Jacks.kicad_sch, cv_sequencer.kicad_pcb, cv_sequencer.kicad_sch]
2022-03-10 added gitignore to not track backups
2022-03-10 fleshed out a lot of the MCU circuitry
    [IO_Jacks.kicad_sch, cv_sequencer.kicad_sch]
2022-03-10 worked on gate input circuitry
    [IO_Jacks.kicad_sch, cv_sequencer.kicad_sch]
2022-03-11 finished schematic (still needs double checking)
    [IO_Jacks.kicad_sch, cv_sequencer.kicad_sch]
2022-03-11 ran ERC, minimal errors. Imported footprints and started grouping them
    [IO_Jacks.kicad_sch, cv_sequencer.kicad_pcb, cv_sequencer.kicad_sch]
2022-03-14 more work on pcb, added some TODO notes to schematic
    [IO_Jacks.kicad_sch, cv_sequencer.kicad_pcb, cv_sequencer.kicad_sch]
2022-03-14 Changed encoder to SMD version
    [IO_Jacks.kicad_sch, cv_sequencer.kicad_pcb, cv_sequencer.kicad_sch]
2022-03-15 gots most components placed nicely, added 4027 for MIDI, still to finish
    [IO_Jacks.kicad_sch, cv_sequencer.kicad_pcb, cv_sequencer.kicad_sch]
2022-03-15 Made minor tweaks, started routing of board
    [IO_Jacks.kicad_sch, cv_sequencer.csv, cv_sequencer.kicad_pcb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]
2022-03-16 some more routing
    [IO_Jacks.kicad_sch, cv_sequencer.kicad_pcb, cv_sequencer.kicad_sch]
2022-03-16 Added a few 0 ohm options, finished routing, ordered board!
    [IO_Jacks.kicad_sch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]
2022-03-28 updated jack and encoder footprints with user drawing layer
    [cv_sequencer.kicad_pcb]
2022-04-07 Started firmware. Didn't realize RP2040 needed external flash. But luckily found linker script that can load and execute code straight from RAM
    [cv_sequencer-User_Drawings.dxf, cv_sequencer-User_Eco1.dxf, cv_sequencer.kicad_pcb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]
2022-04-07 minimal example with LCD and button working. Stop tracking build artifacts
2022-06-23 Added README and PCB rev1 photos
2023-01-18 Verified that DAC is recieving SPI transactions and outputing correctly!
    [main.rs, mcp48fxbxx.rs]
2023-01-22 Changes from a while ago
    [IO_Jacks.kicad_sch, cv_sequencer.csv, cv_sequencer.kicad_pcb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]
2023-01-22 Added USB other-side connections to schematic
    [cv_sequencer.kicad_sch]
2023-01-24 Added QSPI Flash to Schematic
    [IO_Jacks.kicad_sch, cv_sequencer.kicad_sch]
2023-01-24 Started re-route of PCB
    [cv_sequencer.kicad_pcb, cv_sequencer.kicad_sch]
2024-09-10 updated to KiCad v8
    [IO_Jacks.kicad_sch, cv_sequencer.kicad_pcb, cv_sequencer.kicad_sch]
